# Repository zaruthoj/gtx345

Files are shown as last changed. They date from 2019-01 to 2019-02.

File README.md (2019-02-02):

# Simulated Garmin GTX345 Transponder

This is a simulated Garmin GTX345 Transponder I designed for my home simulator. So far it's working well for me!  I've attempted to match the real unit as exactly as possible using commonly available tools and materials.

## Status

The hardware is complete and functional.  The softare is still a work in progress, though the major UI and sim connection features are done.

I've got 4 extra PCBs in hand.  Contact zaruthoj at gmail if you want one.  I'd be happy to sell them for $10 each plus shipping.

### TODO

* Add timer pages
* Add altitude alerting pages
* Add support for saving settings to EEPROM

## Assembly

* [BOM](doc/bom.md)
* Soldering (coming soon)
* [3D Printing](doc/printing.md)
* [Finishing](doc/finishing.md)
* Final Assembly (coming soon)

## Compatibility

I'm using this with P3Dv3 running the [PilotEdge](https://www.pilotedge.net/) Client and FSUIPC.  Additional work would be required to interface this with XPlane.  However, I've designed this in a modular way such that it should be straightforward to implement an XPlane interface.

## Equipment

### Required

* 3D Printer
* Soldering Iron
* 100, 200, and 400 grit sandpaper.

### Recommended

* Soldering Hot Air or Reflow (It's possible to use an iron on these SMD components, but is much harder.)
* Dremel with 100 and 200 grit sanding bits.  For sanding the recessed area around the screen.
* 100 grit diamond needle files.  For sanding the recessed area around the screen.

### Optional

* Random Orbital Sander.  This makes sanding the face and sides so much faster.
* XTC-3D 3d print coating.  If there are larger defects in the face of your print, this stuff works wonders.  I used it to fill in some areas around the circular buttons that failed to print correctly.

## Skills Required

* 3D printing
* SMD and thru hole soldering.
* Basic familiarity with uploading software to Arduinos.

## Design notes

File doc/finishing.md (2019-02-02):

# Finishing

## Sanding

Sand the front and sides of the frame and all the buttons.  Work your way up from 100 to 200 to 400 grit sandpaper.  Wet sanding works much better than dry sanding.  Spend most of your time getting rid of all the ridges with the 100 grit paper.

A _carefully_ used dremel with sanding bits can help with the screen recess area.  Go slowly though.  It's really easy to screw up this way.  Finish up the areas that the Dremel can't reach with needle point diamond files.  Be sure to do this before you sand the face.  It's easy to slip and scratch your beautifully smooth face.

Either lightly sand the insides of the button holes or skip them entirely.  I didn't sand them.  If you do, be very careful in the areas where the frame is thin, as it's really easy to overdo it and enlarge the hole.

A random orbital sander will make short work of the frame.  If you don't have one, use a sheet of sandpaper on a glass surface to make sure it's flat.  It will take forever, but the results will be good.

## XTC-3D (Optional)

If you have major defects on the face of the frame that you can't sand out, try XTC-3D after you've rough sanded with 100 grit.  Spread it evenly across the surface, being careful not to let any spill into the button holes.  Wipe any that does get in the button holes with a paper towel.  Also be careful not to use too much inside the screen recess.  It will pool in the corners and mess up the look of the recess.

Wait 12-24 hours for it to cure, and sand it aggressively with 100 grit until you have a smooth, even surface.

## Filler Primer

This step is optional if you used XTC-3D.  Filler primer is great for willing in all the tiny gaps a 3d printer leaves.  Spray 2 light coats on the front and sides of the frame.  Follow the instructions on the can for recoat and drying times.

It's not necessary to use filler primer on the buttons, as you'll be applying decals that will cover up the imperfections.

## Paint

Paint all visible surfaces with matte black spray paint.  Use light coats sprayed from all angles to make sure you cover the insides of the button holes.  It's much better to do multiple light coats instead of heavy coats.

## Decals

Follow the instructions on your pack of waterslide decal transfer paper to print the [decals](../labels.pdf).  Make sure you use a laser printer at the highest detail settings you can.  Also, some laser printers are hotter than others, and may melt the decal paper to the fuser.  Maybe don't do this on your expensive office printer.  Use at your own risk!

Cut out one set of decals with scissors.  Try to get as close to the black edge as you can.  Don't worry if your cut out decals have a bit of white showing on the edges.  We'll touch that up later.

Follow your decal's instructions to apply them  I recommend a pair of fine tweezers, as these things are really tiny.

The decal set has 3x as many as you need just in case you screw up.

Let the decals dry for 4 hours.  Then, take a sharpie and carefully touch up the edges where any white is showing.  Be sure to avoid getting sharpie on the white text though!

## Clear Coat

Apply 1-2 coats of clear coat.  Once it's dry, you're done!

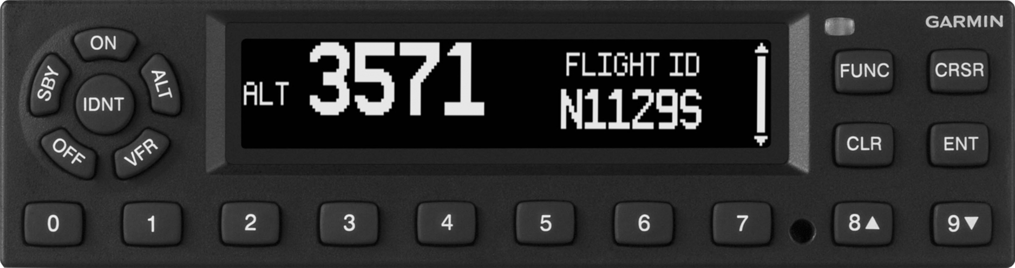
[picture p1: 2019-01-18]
pin_header/gtx345.png

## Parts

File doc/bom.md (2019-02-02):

| Description | Quantity  | Price | Manufacturer  | Part # | Link  |
|--- |--- |--- |--- |---  |---  |
| Arduino Nano[1] | 1 | 13.86 | Elegoo | | [Amazon](https://www.amazon.com/gp/product/B0713XK923/ref=oh_aui_search_asin_title?ie=UTF8&psc=1) |
| Voltage Shifter | 1 | 0.44  | Texas Instruments | SN74LVC245ANSR | [Digikey](https://www.digikey.com/product-detail/en/texas-instruments/SN74LVC245ANSR/296-13632-1-ND/499513) |
| Momentary Button  | 20 | 0.415 | Nidec Copal | TR1-01 | [Digikey](https://www.digikey.com/product-detail/en/nidec-copal-electronics/TR1-01/563-1932-5-ND/5125294) |
| OLED Screen | 1 | 34.65 | Newhaven Display  | NHD-3.12-25664UCB2 | [Digikey](https://www.digikey.com/product-detail/en/newhaven-display-intl/NHD-3.12-25664UCB2/NHD-3.12-25664UCB2-ND/2640785) |
| I/O Expander  | 1 | 4.68  | Cypress Semiconductor Corp | CY8C9520A-24PVXI  | [Digikey](https://www.digikey.com/product-detail/en/cypress-semiconductor-corp/CY8C9520A-24PVXI/428-2015-5-ND/1640246) |
| 3.3V Regulator | 1 | 1.22  | Texas Instruments | LM3671MF-3.3/NOPB | [Digikey](https://www.digikey.com/product-detail/en/texas-instruments/LM3671MF-3.3-NOPB/LM3671MF-3.3-NOPBCT-ND/1590190) |
| 2.2uH Inductor | 1 | 0.20  | Taiyo Yuden | NRH2412T2R2MNGH | [Digikey](https://www.digikey.com/product-detail/en/taiyo-yuden/NRH2412T2R2MNGH/587-3443-1-ND/4157783) |
| 10uF 0805 Capacitor[2] | 1 | 0.21  | Samsung Electro-Mechanics | CL21A106KOQNNNE | [Digikey](https://www.digikey.com/product-detail/en/samsung-electro-mechanics/CL21A106KOQNNNE/1276-1096-1-ND/3889182) |
| 22uF 0805  Capacitor[2] | 1 | 0.38  | Samsung Electro-Mechanics | CL21A226MOCLRNC | [Digikey](https://www.digikey.com/product-detail/en/samsung-electro-mechanics/CL21A226MOCLRNC/1276-6780-1-ND/5961639) |
| 0.1uF 0805 Capacitor[2] | 2 | 0.13  | Samsung Electro-Mechanics | CL21B104KBCSFNC | [Digikey](https://www.digikey.com/product-detail/en/samsung-electro-mechanics/CL21B104KBCSFNC/1276-2446-1-ND/3890532) |
| 4.7k 0805 resistor[2] | 4 | 0.09  | Yageo | RC0805JR-074K7L | [Digikey](https://www.digikey.com/product-detail/en/yageo/RC0805JR-074K7L/311-4.7KARCT-ND/731274) |
| Pin Header Strip[2] | 1 | 0.64  | Sullins Connector | PRPC040SFAN-RC | [Digikey](https://www.digikey.com/product-detail/en/sullins-connector-solutions/PRPC040SFAN-RC/S1211EC-40-ND/2775334) |
| Jumper Wires[2] | 1 | 1.95  | Sparkfun  | PRT-12796 | [Digikey](https://www.digikey.com/product-detail/en/sparkfun-electronics/PRT-12796/1568-1513-ND/5993861)  |
| M3x8 Screws[2] | 6 | 17.99 | Comdox | M2 M3 M4 Assortment | [Amazon](https://www.amazon.com/gp/product/B01MT836J4/ref=oh_aui_search_asin_title?ie=UTF8&psc=1) |
| M3x12 Screws[2] | 2 | | Comdox | | [Amazon](https://www.amazon.com/gp/product/B01MT836J4/ref=oh_aui_search_asin_title?ie=UTF8&psc=1) |
| M2x8 Screws[2] | 2 | | Comdox | | [Amazon](https://www.amazon.com/gp/product/B01MT836J4/ref=oh_aui_search_asin_title?ie=UTF8&psc=1) |
| Waterslide Laser Decal Paper  | 1 | 9.99  | Sunnyscopa | | [Amazon](https://www.amazon.com/gp/product/B075R1WSBL/ref=oh_aui_search_asin_title?ie=UTF8&psc=1) |
| Filler Primer[2]  | 1 | 4.24  | Rustoleum | | [Walmart](https://www.walmart.com/ip/Rust-oleum-Gray-Filler-Primer/33616414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) |
| Matte Black Spray Paint[2] | 1 | 5.68  | Rustoleum | | [Lowes](https://www.amazon.com/Rust-Oleum-245198-Universal-Surface-12-Ounce/dp/B0016HLAGE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) |
| Matte Clear Coat[2] | 1 | 3.98  | Rustoleum | | [Amazon](https://www.amazon.com/Rust-Oleum-249087-Painters-Purpose-12-Ounce/dp/B002BWORZE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) |

Total Cost: $109.99

Total Cost assuming you have generic components on hand: $73.14

[1] Do not purchase the official Arduino Nano.  It comes with the pin headers installed on the wrong side for this project.  Make sure that whatever Nano clone you buy comes with the pin headers uninstalled.  If the Nano you buy does not come with pin headers, buy an extra pin header strip.

[2] These are generic components.  Links and part numbers are included for reference.  Reasonable substitutions should be fine.

I strongly recommend that you buy 1-2 extras of each electronic component other than the screen.  It's cheap insurance in case you damage or lose one.  Paying for shipping again and being dead in the water for 1-2 weeks because you smoked a 50 cent chip is a terrible experience.

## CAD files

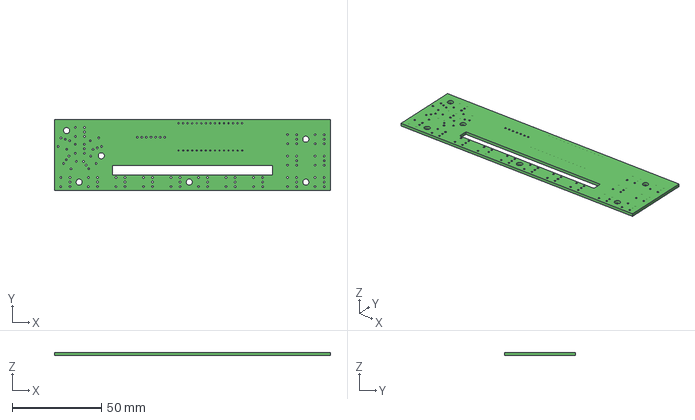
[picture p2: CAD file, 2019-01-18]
pcb/pcb.step
154.4 x 39.7 x 1.60 mm

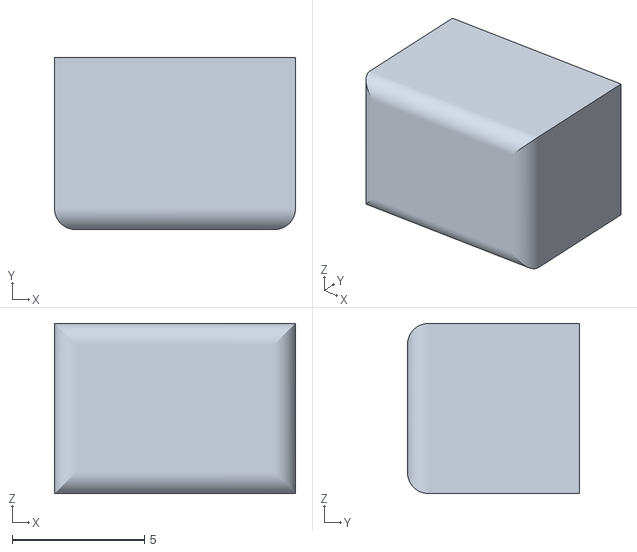
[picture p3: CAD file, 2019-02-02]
stl/rec_button.stl
9.10 x 6.50 x 6.42

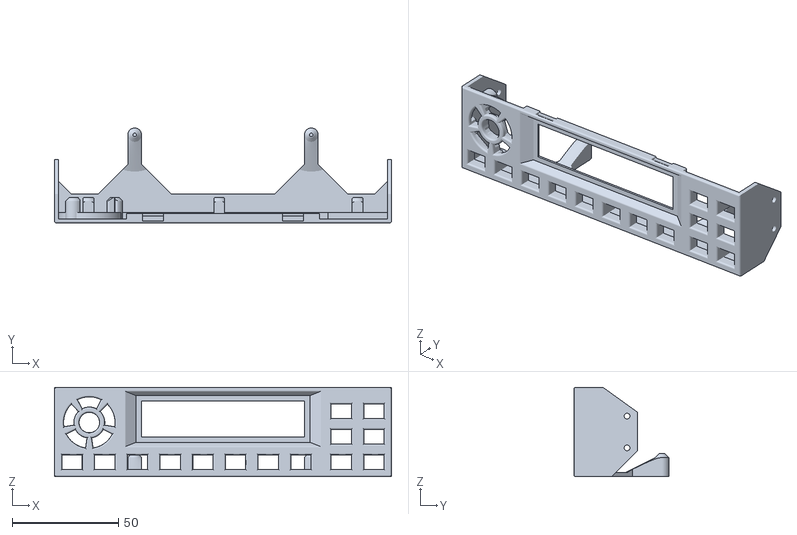
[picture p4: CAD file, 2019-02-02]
stl/frame.stl
158.8 x 44.8 x 42.1

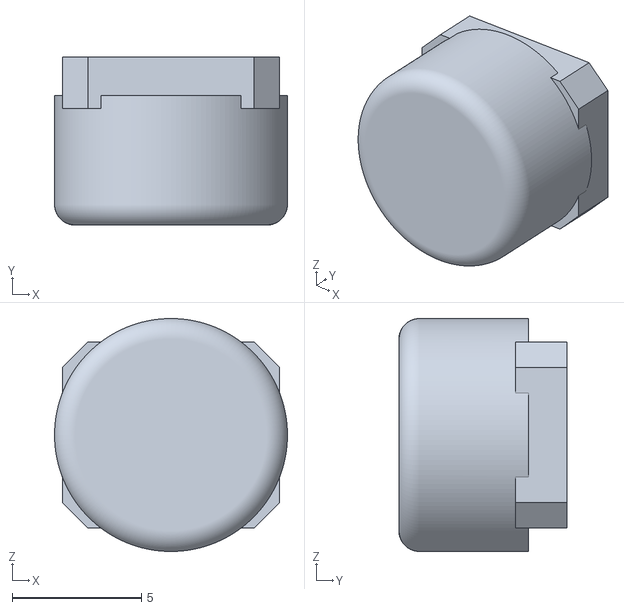
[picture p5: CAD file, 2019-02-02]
stl/circle_button.stl
9.00 x 6.50 x 9.00

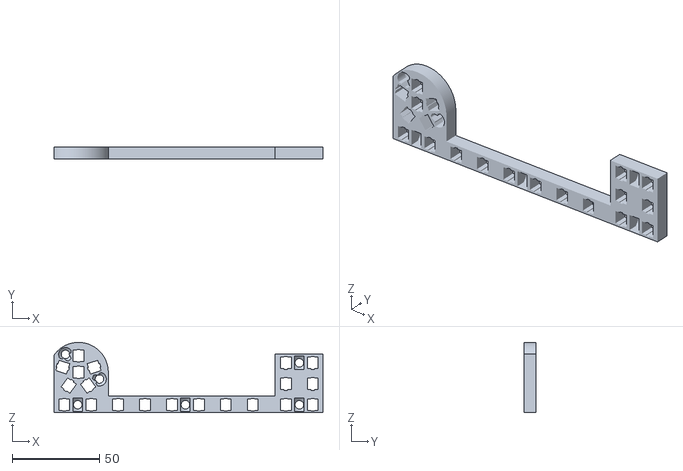
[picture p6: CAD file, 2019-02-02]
stl/guide.stl
154.0 x 7.00 x 40.2

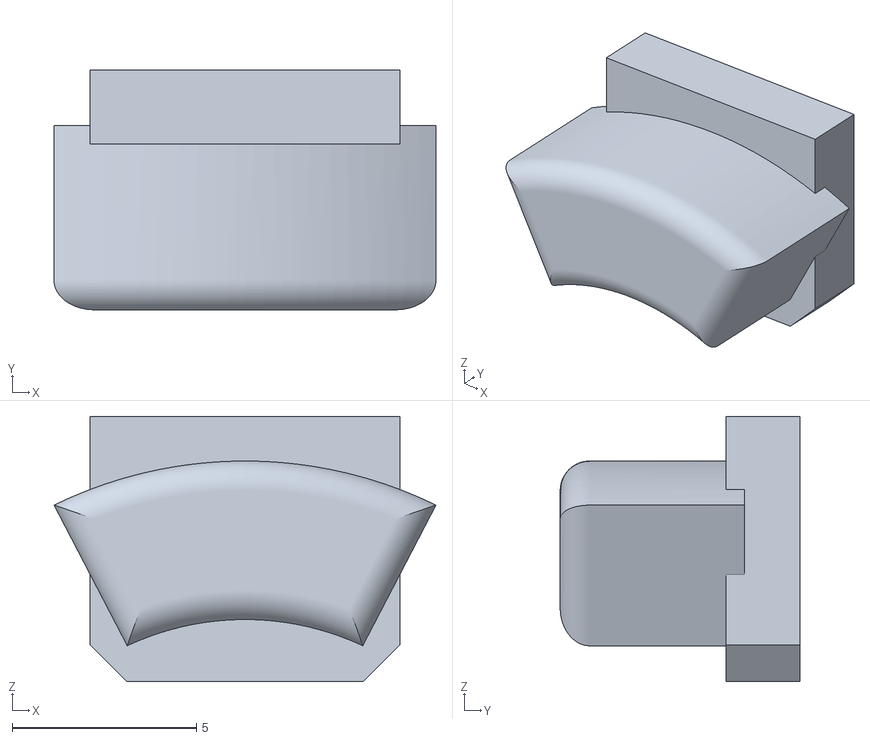
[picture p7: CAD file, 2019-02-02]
stl/arc_button.stl
10.4 x 6.50 x 7.20

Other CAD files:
pin_header/pcb.step

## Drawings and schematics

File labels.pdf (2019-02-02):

0

1 | 2 | 3

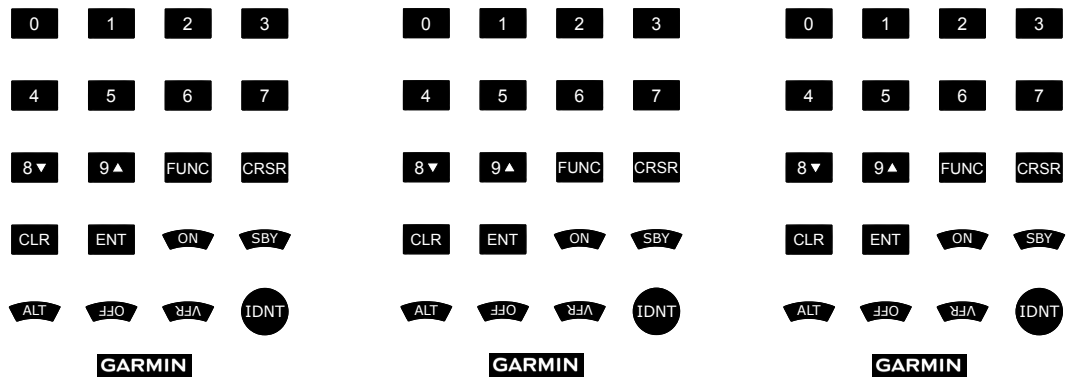
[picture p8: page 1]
FUNC; CRSR; CLR; ENT; IDNT; SBY; ALT; OFF; VFR

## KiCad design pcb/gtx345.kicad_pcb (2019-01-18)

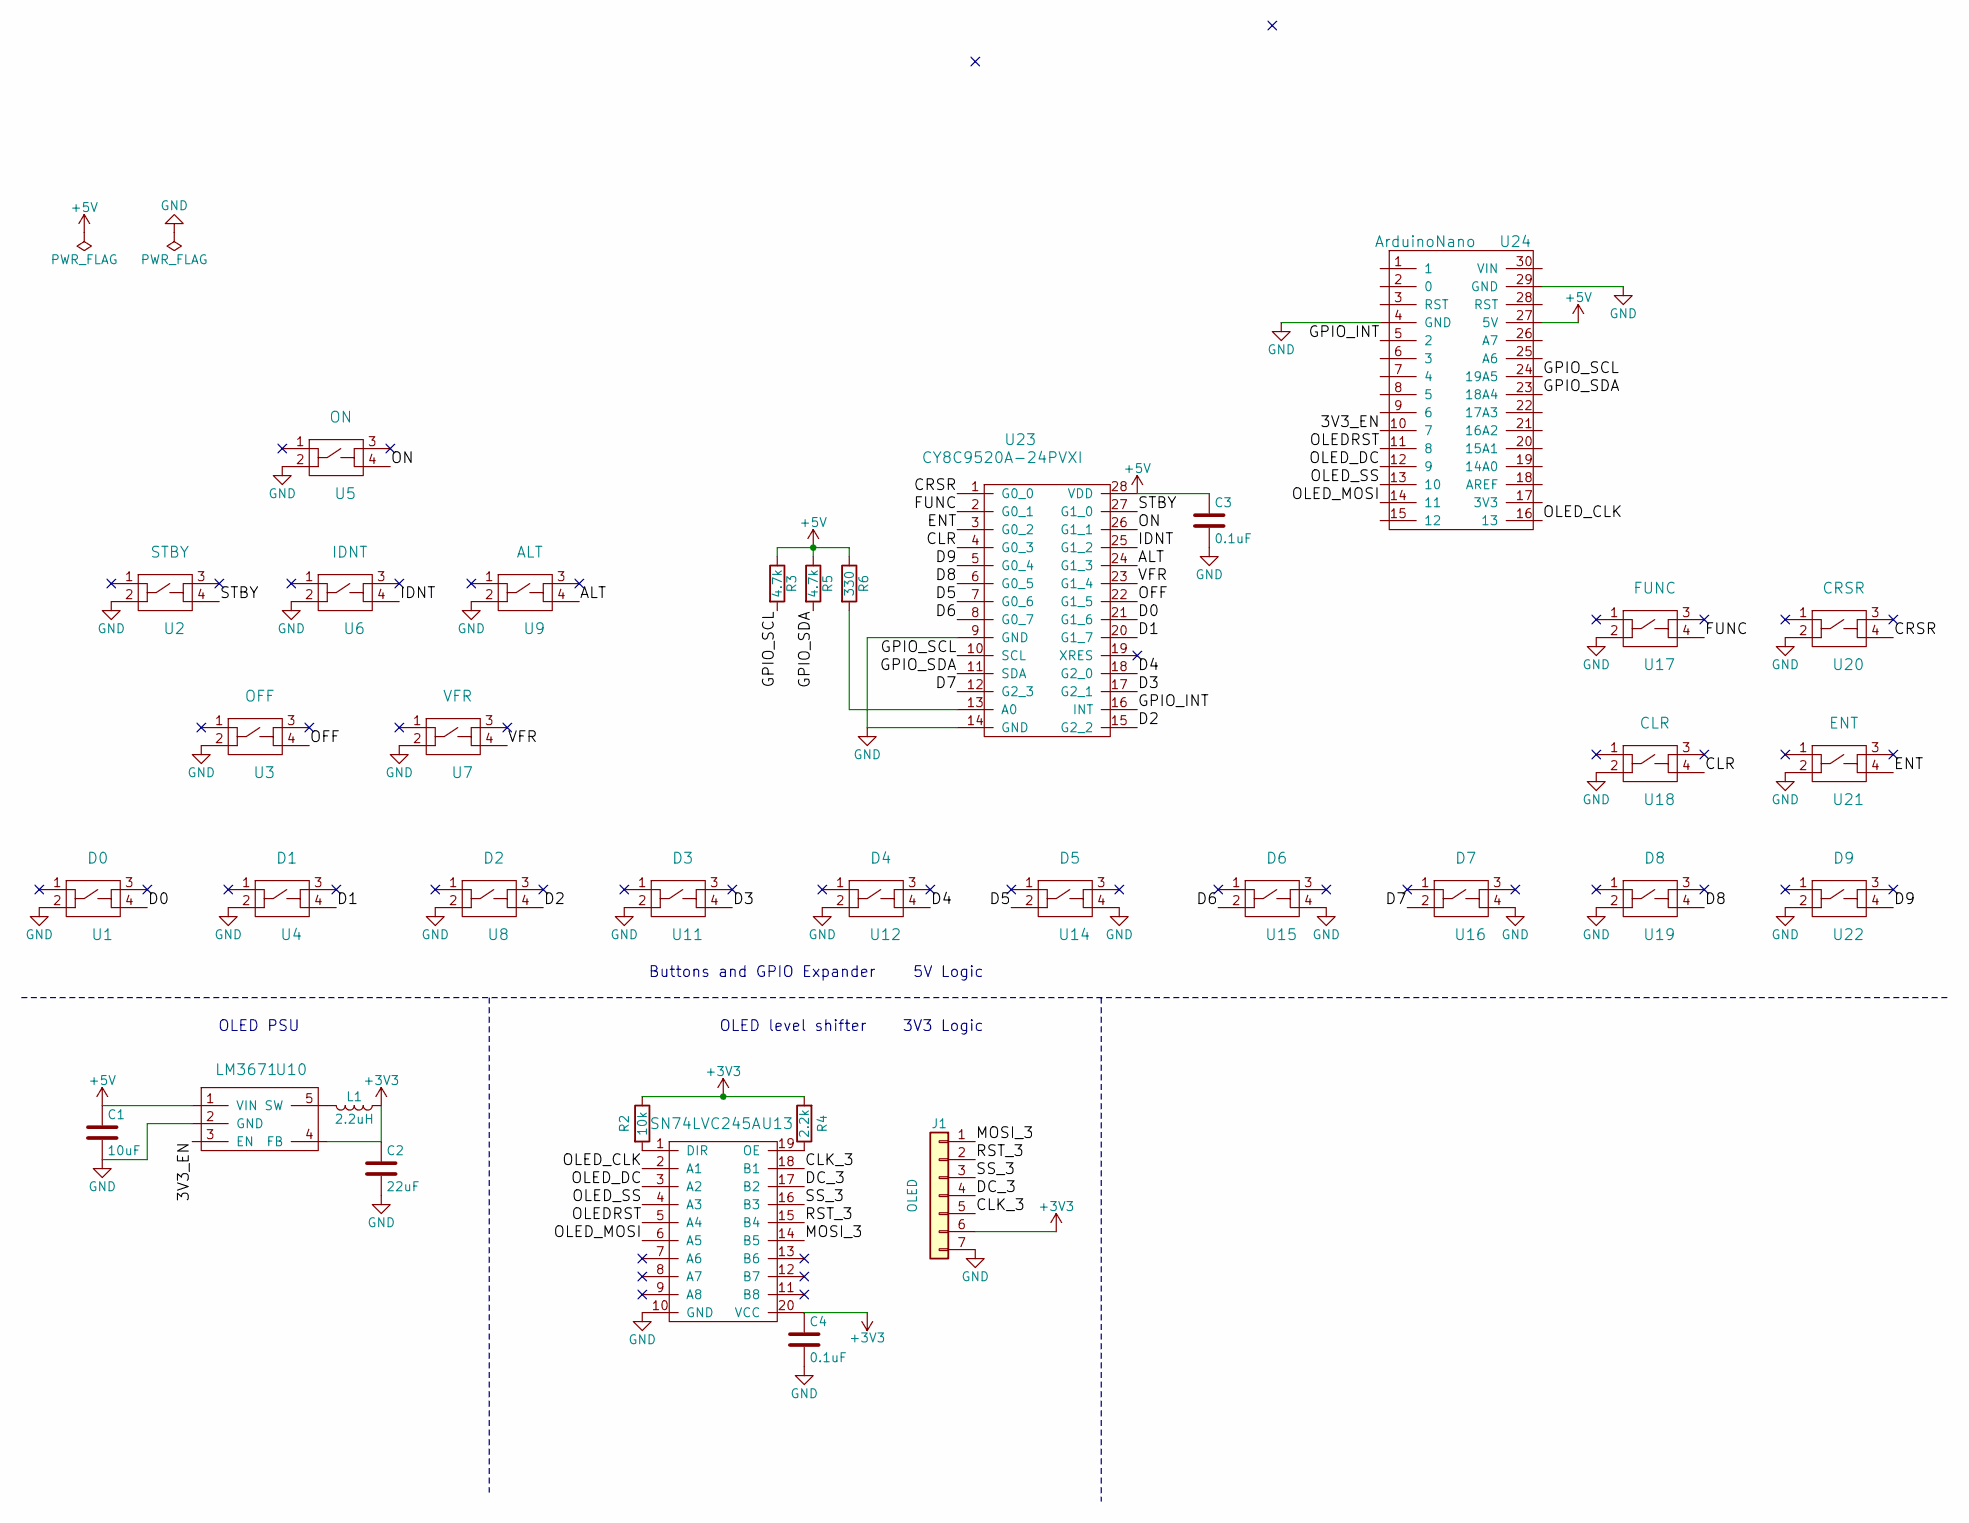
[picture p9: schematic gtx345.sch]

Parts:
C1: 10uF; C_0805_HandSoldering
C2: 22uF; C_0805_HandSoldering
C3, C4: 0.1uF; C_0805_HandSoldering
J1: OLED; Pin_Header_Straight_1x07_Pitch2.54mm
L1: 2.2uH; Inductor_NRH2412
R2: 10k; R_0805_HandSoldering
R3, R5: 4.7k; R_0805_HandSoldering
R4: 2.2k; R_0805_HandSoldering
R6: 330; R_0805_HandSoldering
U1: D0; Nidec_TR1_Button
U2: STBY; Nidec_TR1_Button
U3: OFF; Nidec_TR1_Button
U4: D1; Nidec_TR1_Button
U5: ON; Nidec_TR1_Button
U6: IDNT; Nidec_TR1_Button
U7: VFR; Nidec_TR1_Button
U8: D2; Nidec_TR1_Button
U9: ALT; Nidec_TR1_Button
U10: LM3671; SOT-23-5_HandSoldering
U11: D3; Nidec_TR1_Button
U12: D4; Nidec_TR1_Button
U13: SN74LVC245A; SOIC-20W_5.3x12.8mm_Pitch1.27mm
U14: D5; Nidec_TR1_Button
U15: D6; Nidec_TR1_Button
U16: D7; Nidec_TR1_Button
U17: FUNC; Nidec_TR1_Button
U18: CLR; Nidec_TR1_Button
U19: D8; Nidec_TR1_Button
U20: CRSR; Nidec_TR1_Button
U21: ENT; Nidec_TR1_Button
U22: D9; Nidec_TR1_Button
U23: CY8C9520A-24PVXI; 28_SSOP
U24: ArduinoNano; Arduino_Nano

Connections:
+3V3: C2.1, C4.1, J1.6, L1.1, R2.1, R4.2, U10.4 (FB), U13.20 (VCC)
+5V: C1.1, C3.1, R3.1, R5.1, R6.1, U10.1 (VIN), U23.28 (VDD), U24.27 (5V)
/3V3_EN: U10.3 (EN), U24.10 (7)
/ALT: U9.4, U23.24 (G1_3)
/CLK_3: J1.5, U13.18 (B1)
/CLR: U18.4, U23.4 (G0_3)
/CRSR: U20.4, U23.1 (G0_0)
/D0: U1.4, U23.21 (G1_6)
/D1: U4.4, U23.20 (G1_7)
/D2: U8.4, U23.15 (G2_2)
/D3: U11.4, U23.17 (G2_1)
/D4: U12.4, U23.18 (G2_0)
/D5: U14.2, U23.7 (G0_6)
/D6: U15.2, U23.8 (G0_7)
/D7: U16.2, U23.12 (G2_3)
/D8: U19.4, U23.6 (G0_5)
/D9: U22.4, U23.5 (G0_4)
/DC_3: J1.4, U13.17 (B2)
/ENT: U21.4, U23.3 (G0_2)
/FUNC: U17.4, U23.2 (G0_1)
/GPIO_INT: U23.16 (INT), U24.5 (2)
/GPIO_SCL: R3.2, U23.10 (SCL), U24.24 (19A5)
/GPIO_SDA: R5.2, U23.11 (SDA), U24.23 (18A4)
/IDNT: U6.4, U23.25 (G1_2)
/MOSI_3: J1.1, U13.14 (B5)
/OFF: U3.4, U23.22 (G1_5)
/OLEDRST: U13.5 (A4), U24.11 (8)
/OLED_CLK: U13.2 (A1), U24.16 (13)
/OLED_DC: U13.3 (A2), U24.12 (9)
/OLED_MOSI: U13.6 (A5), U24.14 (11)
/OLED_SS: U13.4 (A3), U24.13 (10)
/ON: U5.4, U23.26 (G1_1)
/RST_3: J1.2, U13.15 (B4)
/SS_3: J1.3, U13.16 (B3)
/STBY: U2.4, U23.27 (G1_0)
/VFR: U7.4, U23.23 (G1_4)
GND: C1.2, C2.2, C3.2, C4.2, J1.7, U1.2, U2.2, U3.2, U4.2, U5.2, U6.2, U7.2, U8.2, U9.2, U10.2 (GND), U11.2, U12.2, U13.10 (GND), U14.4, U15.4, U16.4, U17.2, U18.2, U19.2, U20.2, U21.2, U22.2, U23.9 (GND), U23.14 (GND), U24.4 (GND), U24.29 (GND)
unnamed: L1.2, U10.5 (SW)
unnamed: R2.2, U13.1 (DIR)
unnamed: R4.1, U13.19 (OE)
unnamed: R6.2, U23.13 (A0)

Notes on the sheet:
Buttons and GPIO Expander
5V Logic
OLED level shifter
3V3 Logic
OLED PSU

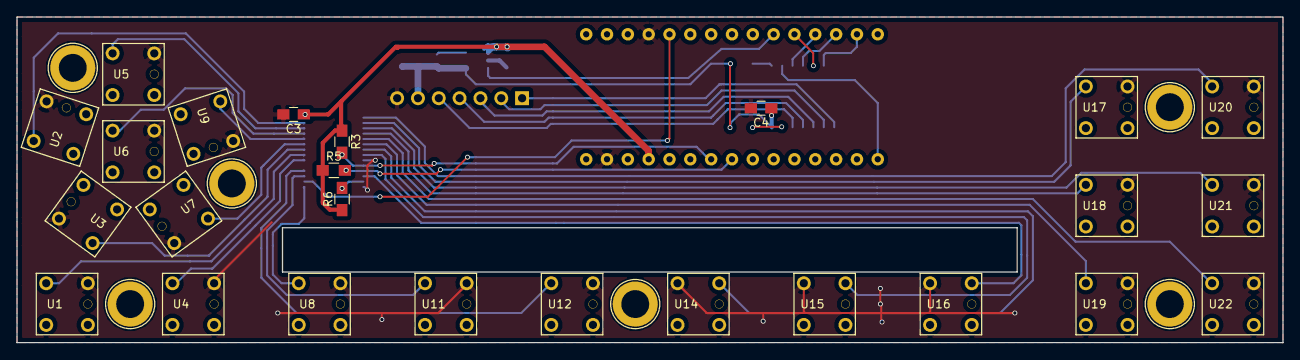
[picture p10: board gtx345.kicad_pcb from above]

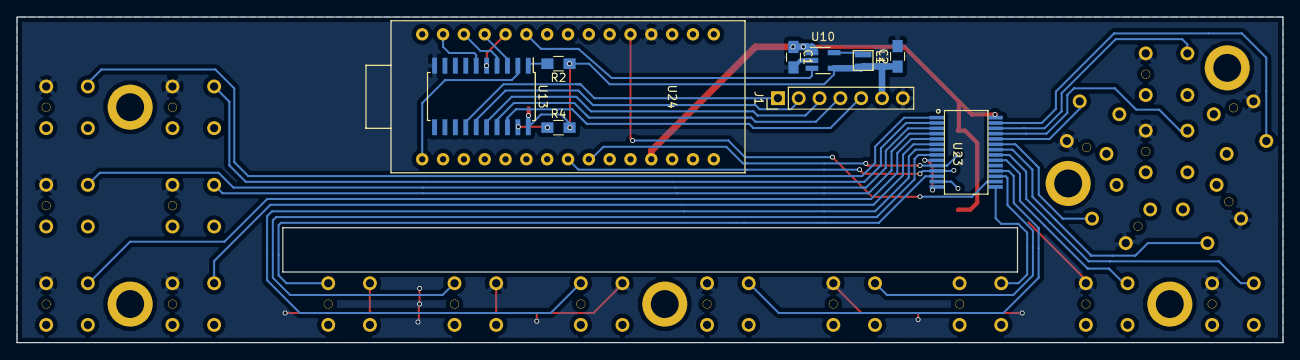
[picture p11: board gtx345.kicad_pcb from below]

Board: 2 copper layers, 154.4 x 39.7 mm, 41 parts (10 on the bottom side), 41 nets.

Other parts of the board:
Ref**: Val**; SCREW_M3
Ref**#2, Ref**#3, Ref**#4, Ref**#5, Ref**#6: Val**; SCREW_M3

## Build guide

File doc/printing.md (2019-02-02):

# 3D Printing

I printed my parts using 1.75mm PLA with a 0.4mm nozzle.  I recommend using whatever settings and material gives you the best results on fine details.  There are some pretty fine walls around the circular button area.

## Parts and Instructions

* [1x Frame](../stl/frame.stl): Print face down using supports.
* [1x Circular Button](../stl/circle_button.stl): Print face down, no supports.
* [5x Arc Buttons](../stl/arc_button.stl): Print face down, no supports.
* [14x Rectangular Buttons](../stl/rec_button.stl): Print face down, no supports.

## Optional Parts

* [1x Button Guide](../stl/guide.stl): This part can be used to ensure that the buttons are soldered on perfectly straight.  This will ensure that the button caps move freely and don't bind on the frame.

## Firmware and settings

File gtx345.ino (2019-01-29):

#include <Wire.h>
#include <Arduino.h>
#include <SPI.h>
#include <U8g2lib.h>
#include "listener.h"
#include "catalog.h"

#define REG_INPUT_PORT_START 0x00
#define REG_OUTPUT_PORT_START 0x08
#define REG_INT_STATUS_START 0x10
#define REG_PORT_SELECT 0x18
#define REG_INT 0x19
#define REG_PORT_DIRECTION 0x1C
#define REG_PULL_UP 0x1D
#define NUM_PORTS 3

#define ENABLE_3V3_PIN 7

#define OLED_RESET 8
#define OLED_DC 9
#define OLED_CS 10
#define OLED_MOSI 11
#define OLED_CLK 13

Controller &controller(bool reset=false) {
  static U8G2_SSD1322_NHD_256X64_1_4W_HW_SPI screen(U8G2_R2, OLED_CS, OLED_DC, OLED_RESET);
  static Controller controller(&screen);
  return controller;
}

void isr();

class CY8C95x0A {
 public:
  CY8C95x0A(uint8_t i2c_address, int interrrupt_pin) :
    interrrupt_pin_(interrrupt_pin),
    i2c_address_(i2c_address),
    triggered_(false) {}

  void check_error(int error) {
    if (error != 0) {
      Serial.print("I2C Error: ");
      Serial.println(error);
    }
  }
  
  void write_reg(uint8_t reg_offset, uint8_t value) {
    Wire.beginTransmission(i2c_address_);
    Wire.write(reg_offset);
    //check_error(Wire.endTransmission(false));
    Wire.write(value);
    check_error(Wire.endTransmission(true));

    delayMicroseconds(100);
    uint8_t check_value = read_reg(reg_offset);
    while(check_value != value) {
      Serial.print("Register ");
      Serial.print(reg_offset);
      Serial.print(" = ");
      Serial.print(check_value);
      Serial.print(". Wrote ");
      Serial.println(value);
      delay(1000);
      check_value = read_reg(reg_offset);
    }
    delayMicroseconds(100);
  }
  
  void read_regs(uint8_t reg_offset, uint8_t num_bytes, uint8_t * output) {
    Wire.beginTransmission(i2c_address_);
    Wire.write(reg_offset);
    check_error(Wire.endTransmission(false));
    Wire.requestFrom(i2c_address_, num_bytes, (uint8_t)true);
    for (int i = 0; i < num_bytes; ++i) {
      output[i] = Wire.read();
    }
  }

  uint8_t read_reg(uint8_t reg_offset) {
    Wire.beginTransmission(i2c_address_);
    Wire.write(reg_offset);
    check_error(Wire.endTransmission(false));
    Wire.requestFrom(i2c_address_, 1, (uint8_t)true);
    uint8_t val = Wire.read();
    return val;
  }

  void scan() {
    if (!triggered_) return;

    uint8_t int_status[NUM_PORTS];
    uint8_t values[NUM_PORTS];
    read_regs(REG_INT_STATUS_START, NUM_PORTS, int_status);
    read_regs(REG_INPUT_PORT_START, NUM_PORTS, values);
    triggered_ = false;
    int_status[2] &= 0x0F;
    for (int i = 0; i < NUM_PORTS; ++i) {
      int changed = -1;
      switch(int_status[i]) {
        case 0x01:
          changed = 0;
          break;
        case 0x02:
          changed = 1;
          break;
        case 0x04:
          changed = 2;
          break;
        case 0x08:
          changed = 3;
          break;
        case 0x10:
          changed = 4;
          break;
        case 0x20:
          changed = 5;
          break;
        case 0x40:
          changed = 6;
          break;
        case 0x80:
          changed = 7;
          break;
        default:
          continue;
      }
      controller().on_event(i << 4 | changed, (int_status[i] & ~values[i]) != 0);
    }
  }
  
  void begin() {
    Wire.begin();
    attachInterrupt(digitalPinToInterrupt(interrrupt_pin_), isr, RISING);
    for(uint8_t port_num = 0; port_num < NUM_PORTS; ++port_num) {
      write_reg(REG_OUTPUT_PORT_START + port_num, 0);
      write_reg(REG_PORT_SELECT, port_num);
      write_reg(REG_PORT_DIRECTION, 0xff);
      write_reg(REG_PULL_UP, 0xff);
      if (port_num != 2) {
        write_reg(REG_INT, 0x00);
      } else {
        write_reg(REG_INT, 0xF0);
      }
    }
  }

  volatile bool triggered_;
 private:
  int interrrupt_pin_;
  uint8_t i2c_address_;
};


CY8C95x0A expander(0x21, 2);
void isr() {
  expander.triggered_ = true;
}


StatusPage &status_page() {
  static StatusPage internal;
  return internal;
}
SquawkDisplay &squawk_display() {
  static SquawkDisplay internal;
  return internal;
}

StaticText &alt_mode() {
  static StaticText internal("ALT", ALT_X, ALT_Y, ALT_FONT);
  return internal;
}
IdentText &ident_text() {
  static IdentText internal("IDNT", IDNT_X, IDNT_Y, IDNT_FONT);
  return internal;
}
FunctionGroup &xpdr_group() {
  static FunctionGroup internal;
  return internal;
}
FlightId &flight_id() {
  static FlightId internal;
  return internal;
}
FlightIdEdit &flight_id_edit() {
  static FlightIdEdit internal;
  return internal;
}
SerialCom &serial_com() {
  static SerialCom internal;
  return internal;
}

void setup() {
  Serial.begin(115200);
  expander.begin();
  pinMode(ENABLE_3V3_PIN, OUTPUT);
  digitalWrite(ENABLE_3V3_PIN, HIGH);

  controller().add_child(&status_page(), true);
  controller().add_child(&ident_text(), true);
  controller().add_child(&flight_id_edit(), false);
  controller().add_child(&serial_com(), true);
  
  status_page().add_child(&alt_mode(), true);
  status_page().add_child(&squawk_display(), true);
  status_page().add_child(&xpdr_group(), true);

  xpdr_group().add_function(&flight_id());

  controller().begin();
  controller().on_event(EVENT_RENDER);
}

uint32_t last_refresh_ms = 0;
void loop() {
  expander.scan();

  controller().process_event();
  uint32_t now_ms = millis();
  if (now_ms > last_refresh_ms + 100) {
    last_refresh_ms = now_ms;
    controller().on_event(EVENT_TICK);
  }
}

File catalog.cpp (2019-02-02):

#include "catalog.h"
#include "listener.h"

extern Controller &controller(bool reset=false);
extern StaticText &alt_mode();
extern StatusPage &status_page();
extern FlightId &flight_id();
extern FlightIdEdit &flight_id_edit();

void Controller::on_event(Event event_id, bool is_start) {
  event_queue_.unshift(EventData{event_id, is_start});
}

void Controller::process_event() {
  if (event_queue_.isEmpty()) return;
  EventData event = event_queue_.last();
  if (event.event_id == EVENT_RENDER) {
    render();
  } else {
    on_change_event(event.event_id, event.is_start);
    Listener::on_event(event.event_id, event.is_start);
  }
  event_queue_.pop();
}

void Controller::render() {
  if (!power_on_) return;
  screen_->firstPage();
  do {
    Listener::on_event(EVENT_RENDER);
  } while ( screen_->nextPage() );
}

void Controller::on_change_event(Event event_id, bool is_start) {
  if (is_start) {
    switch (event_id) {
      case BUTTON_OFF:
      case BUTTON_ON:
      {
        bool turning_on = event_id == BUTTON_ON;
        if (power_on_ != turning_on) {
          screen_->setPowerSave(!turning_on);
        }
        power_on_ = turning_on;
        on_event(EVENT_RENDER);
        on_event(CHANGE_POWER);
        break;
      }
    }
  }
}

void SerialCom::on_event(Event event_id, bool is_start) {
  char data[5] = {'\0', '\0', '\0', '\0'};
  char cmd[7] = {'\0', '\0', '\0', '\0', '\0', '\0', '\0'};
  char dt[3] = {'\0', '|', '\0'};
  uint8_t len = 1;
  switch (event_id) {
    case CHANGE_SQUAWK:
      strncpy(data, controller().squawk_code_, 5);
      strncpy(cmd, "0x0354", 7);
      dt[0] = 'D';
      Serial.print("UW|");
      len = 4;
      break;
    case CHANGE_ALT:
      data[0] = '0' + !controller().alt_on_;
      strncpy(cmd, "0x7b91", 7);
      dt[0] = 'N';
      Serial.print("UB|");
      break;
    case CHANGE_STANDBY:
      data[0] = '0' + controller().standby_;
      strncpy(cmd, "0x7b91", 7);
      dt[0] = 'N';
      Serial.print("UB|");
      data[0] = controller().standby_;
      break;
    case CHANGE_IDNT:
      strncpy(cmd, "0x7b93", 7);
      dt[0] = 'N';
      Serial.print("UB|");
      data[0] = '1';
      break;
    case EVENT_TICK:
      if (millis() > last_watchdog_ms_ + 1000) {
        last_watchdog_ms_ = millis();
        Serial.println("P3DGTX");
      }
      return;
    case CHANGE_POWER:
    default:
      return;
  }
  Serial.print(cmd);
  Serial.print("|");
  Serial.print(dt);
  Serial.println(data);
}

uint8_t EditTile::get_digit(Event event_id) {
  switch(event_id) {
    case BUTTON_D0:
      return 0;
    case BUTTON_D1:
      return 1;
    case BUTTON_D2:
      return 2;
    case BUTTON_D3:
      return 3;
    case BUTTON_D4:
      return 4;
    case BUTTON_D5:
      return 5;
    case BUTTON_D6:
      return 6;
    case BUTTON_D7:
      return 7;
    case BUTTON_D8:
      return 8;
    case BUTTON_D9:
      return 9;
    default:
      return 255;
  }
}

bool EditTile::is_valid_digit(uint8_t digit) {
  return digit <= 7;
}

void EditTile::exit_entry() {
  edit_digit_ = -1;
  clear_edit_text();
}

void EditTile::apply_digit(char digit) {
  append_edit_text(digit);
  if (edit_digit_ < 0) edit_digit_ = 0;
  ++edit_digit_;
}

void EditTile::clear_digit() {
  edit_digit_--;
  backspace_edit_text();
}

bool EditTile::check_timeouts() {
  if (clear_press_ms_ > 0 && millis() > clear_press_ms_ + 500) {
    edit_digit_ = 0;
    clear_edit_text();
    clear_press_ms_ = 0;
    return true;
  }
  return false;
}

void EditTile::on_change_event(Event event_id, bool is_start) {
  bool should_render = false;
  
  if (is_start) {
    uint8_t digit = get_digit(event_id);
    if (is_valid_digit(digit) && edit_digit_ < length_) {
      apply_digit('0' + digit);
      should_render = true;
    }
    
    if (edit_digit_ >= 0) {
      switch(event_id) {
        case BUTTON_CRSR:
          exit_entry();
          should_render = true;
          break;
        case BUTTON_CLR:
          clear_press_ms_ = millis();
          break;
        case EVENT_TICK:
          should_render |= check_timeouts();
          break;
      }
      if (maybe_set_value(event_id)) {
        exit_entry();
        should_render = true;
      }
    }
  } else if (event_id == BUTTON_CLR) {
    if (clear_press_ms_ > 0) {
      clear_press_ms_ = 0;
      if (edit_digit_ > 0) {
        clear_digit();
        should_render = true;
      } else if (edit_digit_ == 0) {
        exit_entry();
        should_render = true;
      }
    }
  }

  if (should_render) {
    controller().on_event(EVENT_RENDER);
  }
}

void EditTile::render() {
  controller().get_screen()->setDrawColor(1);
  controller().get_screen()->setFont(font_);
  if (edit_digit_ == -1) {
    controller().get_screen()->drawStr(x_, y_, get_value());
  } else {
    controller().get_screen()->setDrawColor(1);
    controller().get_screen()->setFont(font_);
    controller().get_screen()->drawStr(x_, y_, edit_text_);
    for (int i = edit_digit_ + 1; i < length_; ++i) {
      controller().get_screen()->drawGlyph(x_ + char_width_ * i, y_, '_');
    }
    controller().get_screen()->setDrawColor(0);
    controller().get_screen()->drawGlyph(x_ + char_width_ * edit_digit_, y_, get_cursor_char());
  }
}

void SquawkDisplay::on_change_event(Event event_id, bool is_start) {
  if (is_start && event_id == BUTTON_VFR) {
    if (controller().old_code_[0] != '\0' && strcmp(controller().squawk_code_, "1200") == 0) {
      strncpy(controller().squawk_code_, controller().old_code_, 5);
      controller().old_code_[0] = '\0';
    } else {
      strncpy(controller().old_code_, controller().squawk_code_, 5);
      strncpy(controller().squawk_code_, "1200", 5);
    }
    exit_entry();
    controller().on_event(CHANGE_SQUAWK);
    controller().on_event(EVENT_RENDER);
  }
  EditTile::on_change_event(event_id, is_start);
}

bool SquawkDisplay::maybe_set_value(Event event_id) {
  if (edit_digit_ >= length_) {
    strncpy(controller().squawk_code_, edit_text_, 5);
    controller().on_event(CHANGE_SQUAWK);
    return true;
  }
  return false;
}

char * SquawkDisplay::get_value() {
  return controller().squawk_code_;
}

void StaticText::render() {
  controller().get_screen()->setDrawColor(1);
  controller().get_screen()->setFont(font_);
  controller().get_screen()->drawStr(x_, y_, text_);
}

void StatusPage::on_change_event(Event event_id, bool is_start) {
  if (event_id == BUTTON_ALT && is_start) {
    toggle_child(&alt_mode());
    controller().alt_on_ = !controller().alt_on_;
    controller().on_event(EVENT_RENDER);
    controller().on_event(CHANGE_ALT);
  }
}
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

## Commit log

2019-02-02 Fixed screen size issues, moved gerber files, and added documentation.
    [gtx345-B.Cu.gbr, gtx345-B.Mask.gbr, gtx345-B.SilkS.gbr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]
2019-02-02 Fix BOM formatting
2019-02-02 Added STL models, labels pdf, and finishing and printing docs.
    [arc_button.stl, circle_button.stl, frame.stl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]
2019-02-02 Added printing doc link.
